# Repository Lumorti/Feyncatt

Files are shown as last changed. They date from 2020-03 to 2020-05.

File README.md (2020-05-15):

# Feyncatt

### Description

An attempt at a robotic quadruped. At the current stage it's fully printed, able to stand upright and do basic leg movements.

Schrödinger was too obvious a name.

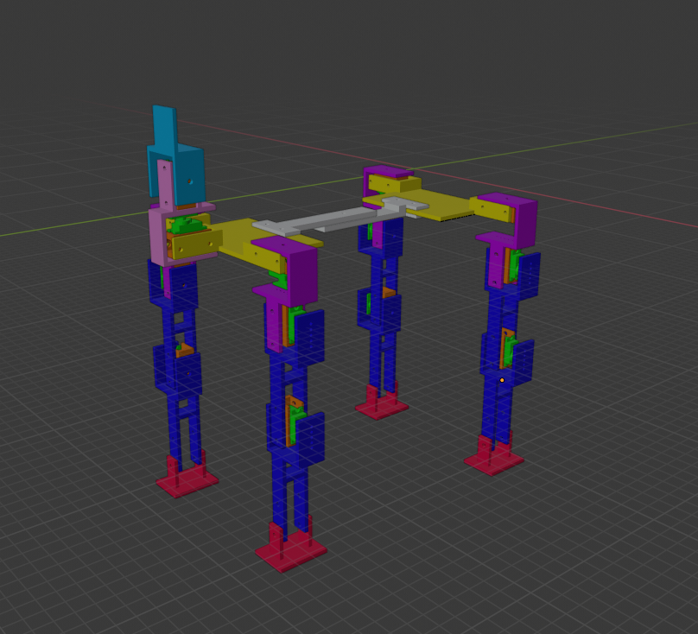
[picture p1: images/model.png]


TODO:
 - attempt a basic walk cycle
 - reprint the feet to be more efficient
 - make the walk cycle more fluid
 - allow turning
 - allow environmental mapping

### Requirements

 - a 3D printer, doesn't need to be a fancy one
 - less than 1 kg of PLA (1 kg allowed me many misprints and redesigns)

 - 14 SG90 servos ([here](https://www.bitsbox.co.uk/index.php?main_page=product_info&cPath=251&products_id=3504))
 - Arduino UNO (or equivalent) ([here](https://www.amazon.co.uk/Arduino-A000066-ARDUINO-UNO-REV3/dp/B008GRTSV6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))
 - MPU6050 Accelerometer/Gyroscope ([here](https://www.bitsbox.co.uk/index.php?main_page=product_info&cPath=302_304&products_id=3059))
 - Ultrasonic range finder ([here](https://www.bitsbox.co.uk/index.php?main_page=product_info&cPath=302_310&products_id=3633))
 - SD card reader and SD card ([here](https://www.bitsbox.co.uk/index.php?main_page=product_info&cPath=347&products_id=2947) and [here](https://www.amazon.co.uk/SanDisk-microSDHC-Memory-Adapter-Performance/dp/B073S9SFK2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))

 - 4xAA battery pack ([here](https://www.bitsbox.co.uk/index.php?main_page=product_info&cPath=192_195_198&products_id=1441))
 - 4 NiMH batteries ([here](https://www.amazon.co.uk/AmazonBasics-Capacity-Pre-Charged-Rechargeable-Batteries-Black/dp/B00HZV9WTM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))
 - boost converter, LCD screen is helpful ([here](https://www.bitsbox.co.uk/index.php?main_page=product_info&cPath=140_171&products_id=3259))
 - 5 A fuse and holder (or not, it's your flammable house) ([here](https://www.bitsbox.co.uk/index.php?main_page=product_info&cPath=214_215_219&products_id=1523) and [here](https://www.bitsbox.co.uk/index.php?main_page=product_info&cPath=214_215_220&products_id=2230))

 - many 1" pin header jumper cables for connecting modules ([here](https://www.bitsbox.co.uk/index.php?main_page=product_info&cPath=225_233&products_id=2909))
 - some wire rated for 5 A as the main power rail ([here](https://www.amazon.co.uk/PsmGoods%C2%AE-Gauge-Silicone-Flexible-Rubber-18/dp/B074299GG5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))
 - switch ([here](https://www.bitsbox.co.uk/index.php?main_page=product_info&cPath=116_136&products_id=911))
 - M4 machine screws/nuts, M3 machine screws/nuts, M2 machine screws/nuts
 
### Printed Parts Required

Can probably all be printed over about a week if you just do a couple parts a day, each part takes about an hour on standard settings.

 - 14 x servoMountV3
 - 8 x servoConnectorStraight
 - 4 x foot
 - 4 x servoConnectorTwist
 - 2 x bodyConnector
 - 1 x bodyBack
 - 1 x bodyFront
 - 1 x servoConnectorHead
 - 1 x servoConnectorNeck

### Build Instructions

- print everything
- figure out all the start/mid/end PWM values for the servos
- assemble the legs
- assemble the body
- assemble the head
- wire up the body
- connect the legs 
- wire up the legs
- connect the head 
- wire up the head
- double check all the wiring
- check it all again
- turn it on, flash the Arduino with the firmware

TODO

### Usage Instructions

TODO

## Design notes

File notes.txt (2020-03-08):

Two main sections of code:
1) neural net trained to recognise certain hand signs
 - follow
 - sleep
 - wait
 - explore
2) code that performs the task specified above by calling functions like "moveForward(10cm)", "turn(-10degrees)", also processes incoming cam data and runs through sobel filter to determine edges, distances etc.

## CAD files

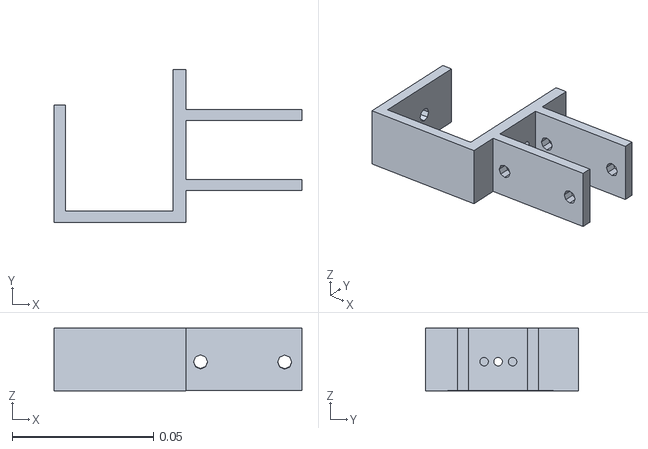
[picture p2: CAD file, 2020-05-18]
stl/servoConnectorNeck.stl
0.0878 x 0.054 x 0.0221

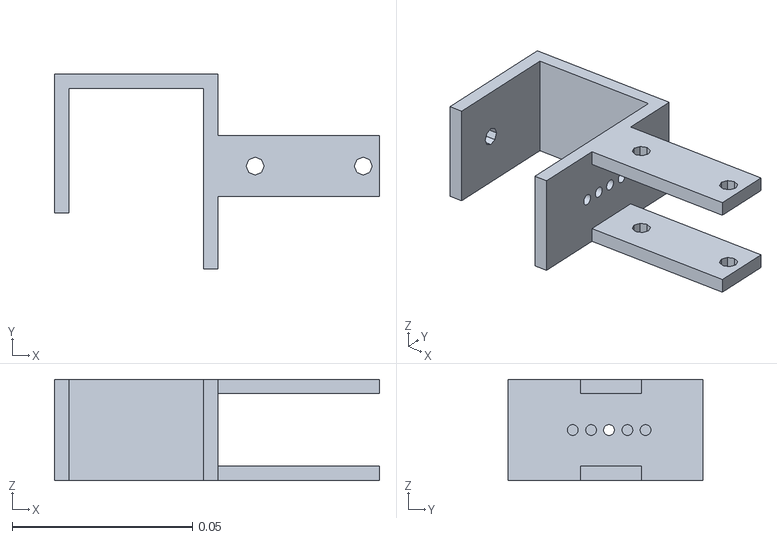
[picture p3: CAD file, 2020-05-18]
stl/servoConnectorTwist.stl
0.0902 x 0.054 x 0.028

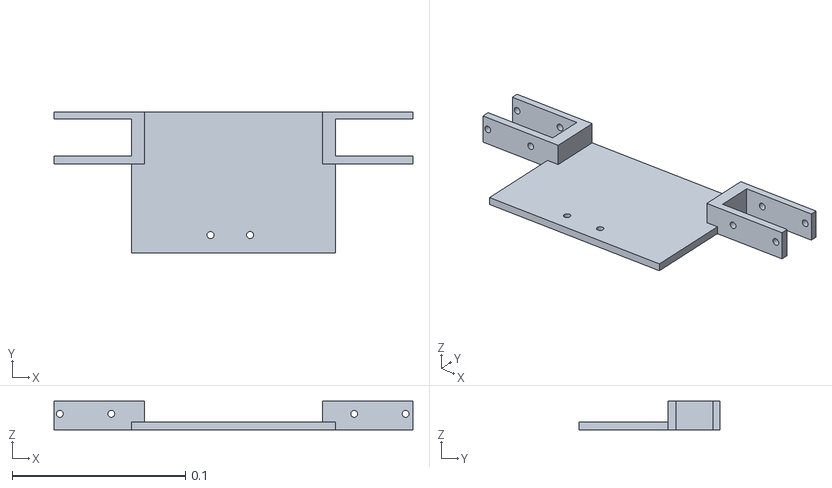
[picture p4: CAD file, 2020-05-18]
stl/bodyBack.stl
0.207 x 0.0816 x 0.0165

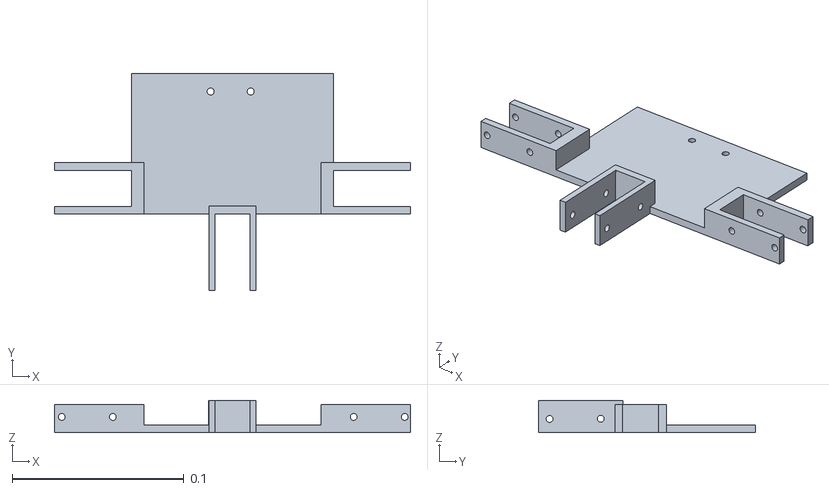
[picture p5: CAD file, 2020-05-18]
stl/bodyFront.stl
0.207 x 0.126 x 0.0189

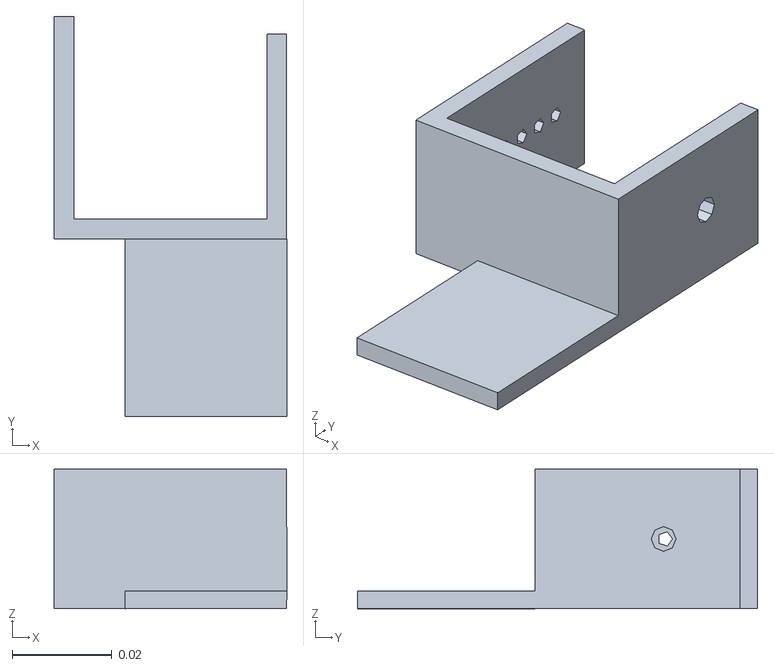
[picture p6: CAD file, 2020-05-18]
stl/servoConnectorHead.stl
0.0467 x 0.0803 x 0.028

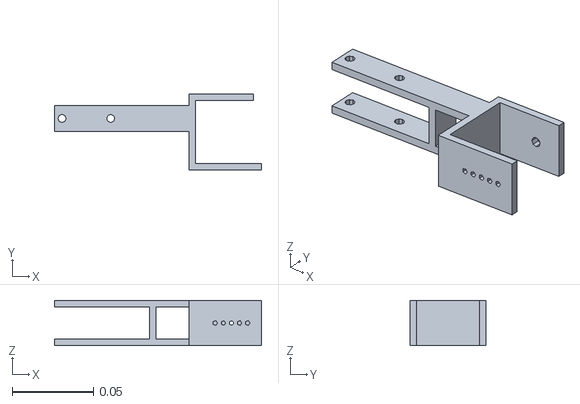
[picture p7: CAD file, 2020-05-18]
stl/servoConnectorStraight.stl
0.128 x 0.0467 x 0.028

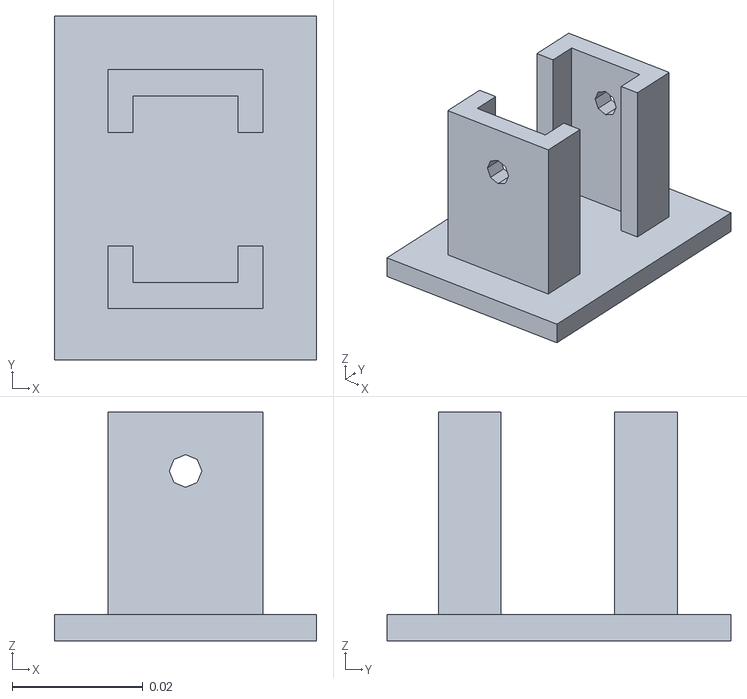
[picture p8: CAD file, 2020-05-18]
stl/footV2.stl
0.0401 x 0.0527 x 0.035

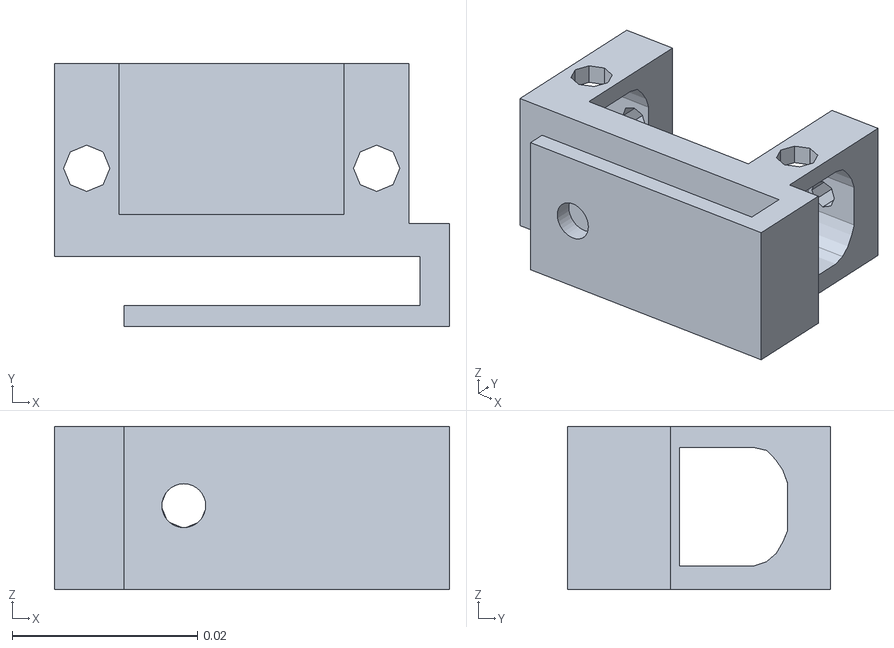
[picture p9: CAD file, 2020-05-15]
stl/servoMountV3.stl
0.0426 x 0.0284 x 0.0176

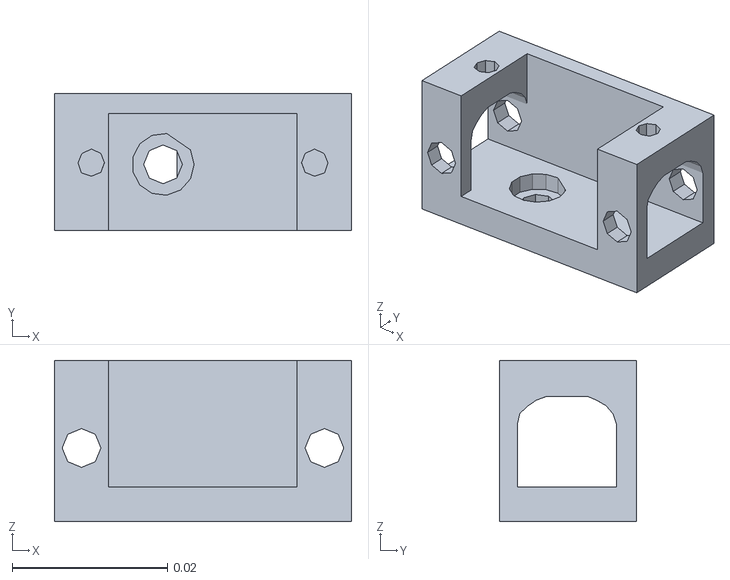
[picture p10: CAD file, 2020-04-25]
stl/servoMountNew.stl
0.0383 x 0.0176 x 0.0208

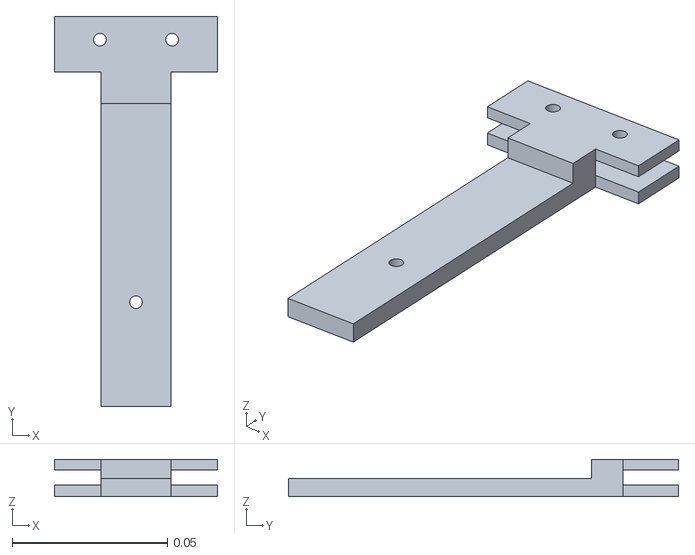
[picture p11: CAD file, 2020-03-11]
stl/bodyConnector.stl
0.0524 x 0.126 x 0.012

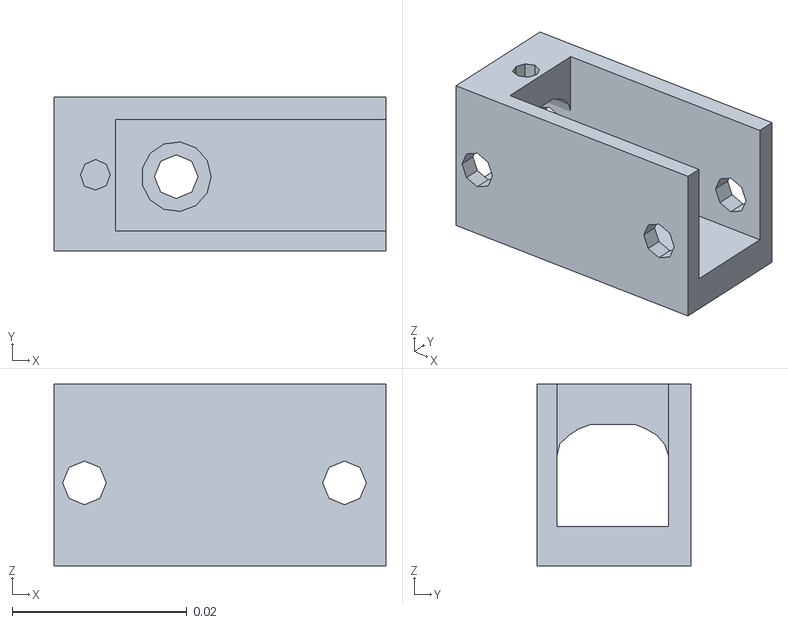
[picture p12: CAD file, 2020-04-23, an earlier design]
stl/servoMount.stl
0.038 x 0.0176 x 0.0208

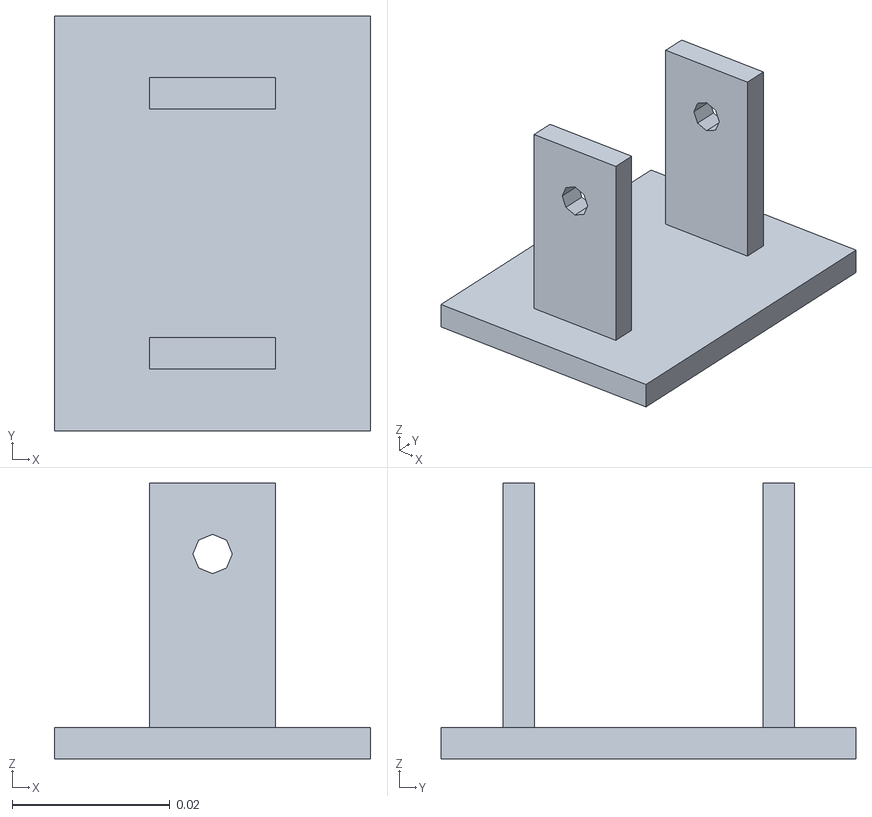
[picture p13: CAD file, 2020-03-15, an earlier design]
stl/foot.stl
0.0401 x 0.0527 x 0.035

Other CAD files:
blender/cat.blend

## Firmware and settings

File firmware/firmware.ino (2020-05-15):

#include <Wire.h>
#include <Adafruit_PWMServoDriver.h>
#include <SD.h>
#include <avr/pgmspace.h>

// Address of the gyro
#define MPU_ADDR 0x68

// Servo properties
#define SERVO_FREQ 50
#define NUM_SERVOS 16
#define QUEUE_SIZE 5
#define NUM_POSITIONS 11
#define AVG_SPEED 100
#define SAVE_POWER false

// Servo pin numbers
#define FRONT_LEFT_HIP      0
#define FRONT_LEFT_KNEE     1
#define FRONT_LEFT_ANKLE    2
#define BACK_LEFT_HIP       4
#define BACK_LEFT_KNEE      5
#define BACK_LEFT_ANKLE     6
#define BACK_RIGHT_HIP      8
#define BACK_RIGHT_KNEE     9
#define BACK_RIGHT_ANKLE    10
#define FRONT_RIGHT_HIP     12
#define FRONT_RIGHT_KNEE    13
#define FRONT_RIGHT_ANKLE   14
#define NECK_VERT           3
#define NECK_HORIZ          15

// Position numbers
#define STOOD_STRAIGHT          0
#define FRONT_LEFT_LEG_UP       1
#define FRONT_RIGHT_LEG_UP      2

// Min and max values for each servo, tweak as necessary
const short minPWM[NUM_SERVOS]   PROGMEM = {110, 120, 120, 0, 130, 150, 110, 0, 105, 120, 120, 0, 120, 120, 110, 0};
const short midPWM[NUM_SERVOS]   PROGMEM = {290, 310, 315, 0, 325, 345, 305, 0, 310, 315, 325, 0, 325, 320, 310, 0};
const short maxPWM[NUM_SERVOS]   PROGMEM = {530, 520, 520, 0, 500, 545, 555, 0, 510, 520, 560, 0, 540, 520, 555, 0};
const short minAngle[NUM_SERVOS] PROGMEM = {-30, -90, -90, 0, -30, -90, -90, 0, -30, -90, -90, 0, -30, -90, -90, 0};
const short maxAngle[NUM_SERVOS] PROGMEM = { 30,  90,  90, 0,  30,  90,  90, 0,  30,  90,  90, 0,  30,  90,  90, 0};

const short positions[NUM_POSITIONS][NUM_SERVOS] PROGMEM = {

  // STOOD_STRAIGHT
  {0,   0,   0, 0, 0,   0,   0, 0, 0,   0,   0,  0, 0,   0,   0, 0},

  // FRONT_LEFT_UP
  {0,  45, -45, 0, 0,   0,   0, 0, 0,   0,   0,  0, 0,   0,   0, 0},
  // FRONT_RIGHT_UP
  {0,   0,   0, 0, 0,   0,   0, 0, 0,   0,   0,  0, 0, -45,  45, 0},
  // BACK_LEFT_UP
  {0,   0,   0, 0, 0,  45, -45, 0, 0,   0,   0,  0, 0,   0,   0, 0},
  // BACK_RIGHT_UP
  {0,   0,   0, 0, 0,   0,   0, 0, 0, -45,  45,  0, 0,   0,   0, 0},

  // WALK1 = FRONT_RIGHT_UP + BACK_LEFT_UP
  {0,   0,   0, 0, 0,  45, -45, 0, 0,   0,   0,  0, 0, -45,  45, 0},

  // WALK2 = FRONT_RIGHT_UP + BACK_LEFT_UP - FRONT_LEFT_UP - BACK_RIGHT_UP
  {0, -45,  45, 0, 0,  45, -45, 0, 0,  45, -45,  0, 0, -45,  45, 0},

  // WALK3 = - FRONT_LEFT_UP - BACK_RIGHT_UP
  {0, -45,  45, 0, 0,   0,   0, 0, 0,  45, -45,  0, 0,   0,   0, 0},

  // WALK1_ALT = FRONT_LEFT_UP + BACK_RIGHT_UP
  {0,  45, -45, 0, 0,   0,   0, 0, 0, -45,  45,  0, 0,   0,   0, 0},

  // WALK2_ALT = FRONT_LEFT_UP + BACK_RIGHT_UP - FRONT_RIGHT_UP - BACK_LEFT_UP
  {0,  45, -45, 0, 0, -45,  45, 0, 0, -45,  45,  0, 0,  45, -45, 0},

  // WALK3_ALT =  - FRONT_RIGHT_UP - BACK_LEFT_UP
  {0,   0,   0, 0, 0, -45,  45, 0, 0,   0,   0,  0, 0,  45, -45, 0},


};

// Main servo controller
Adafruit_PWMServoDriver pwm = Adafruit_PWMServoDriver();

// For I/O
String soFar;
int newValue;
int motorNum;
char incomingByte;

// For accelerometer data
float accelData[3];

// For storing the current angle and the queue of positions
float currentAngles[NUM_SERVOS];
float deltas[NUM_SERVOS];
int stepsLeft = 0;
int numInQueue = 0;
int queue[QUEUE_SIZE * 2];

// Change a servo to an angle
void setServoAngle(uint8_t servoNum, double angle) {

  int actualAngle = min(max(angle, pgm_read_word_near(minAngle + servoNum)), pgm_read_word_near(maxAngle + servoNum));

  if (actualAngle < 0) {
    pwm.setPWM(servoNum, 0, map(actualAngle, -90, 0, pgm_read_word_near(minPWM + servoNum), pgm_read_word_near(midPWM + servoNum)));
  }
  else {
    pwm.setPWM(servoNum, 0, map(actualAngle, 0, 90, pgm_read_word_near(midPWM + servoNum), pgm_read_word_near(maxPWM + servoNum)));
  }

}

void servoStep() {

  // If still have movements to make
  if (stepsLeft > 0) {

    for (int i = 0; i < NUM_SERVOS; i++) {

      currentAngles[i] = currentAngles[i] + deltas[i];

      // Keep any centred servos limp to save power
      if (abs(currentAngles[i]) > 1 || !SAVE_POWER) {
        setServoAngle(i, currentAngles[i]);
      }
      else {
        pwm.setPWM(i, 0, 0);
      }

    }

    stepsLeft = stepsLeft - 1;

  // Otherwise calculate the new deltas
  } else if (numInQueue > 0) {

    stepsLeft = queue[1];
    for (int i = 0; i < NUM_SERVOS; i++) {
      deltas[i] = (float(pgm_read_word_near(&(positions[queue[0]][i]))) - currentAngles[i]) / float(stepsLeft);
    }

    // Shift the queue along
    for (int i = 0; i < QUEUE_SIZE*2 - 2; i += 2) {

      queue[i] = queue[i + 2];
      queue[i + 1] = queue[i + 3];

    }

    numInQueue = numInQueue - 1;

    if (Serial) {
      Serial.println(F("new deltas:"));
      printFloatArray(deltas, NUM_SERVOS);
      Serial.println(F("new queue (removed):"));
      printIntArray(queue, QUEUE_SIZE * 2);
    }

  }

}

void printIntArray(int toPrint[], int arraySize) {

  for (int i = 0; i < arraySize - 1; i++) {
    Serial.print(toPrint[i]);
    Serial.print(", ");
  }
  Serial.println(toPrint[arraySize - 1]);

}

void printFloatArray(float toPrint[], int arraySize) {

  for (int i = 0; i < arraySize - 1; i++) {
    Serial.print(toPrint[i]);
    Serial.print(", ");
  }
  Serial.println(toPrint[arraySize - 1]);

}

// Add a position to the end of the queue
void addToQueue(int pos, int steps) {

  queue[numInQueue * 2] = pos;
  queue[numInQueue * 2 + 1] = steps;
  numInQueue = numInQueue + 1;

  if (Serial) {
    Serial.println("new queue (added):");
    printIntArray(queue, QUEUE_SIZE * 2);
  }

}

// Retrieves the x/y/z accelerometer data
void getAccelData(float values[]) {

  // Accel data
  Wire.beginTransmission(MPU_ADDR);
  Wire.write(0x3B);
  Wire.endTransmission(false);
  Wire.requestFrom(MPU_ADDR, 6, true);
  values[0] = (Wire.read() << 8 | Wire.read()) / 16384.0;
  values[1] = (Wire.read() << 8 | Wire.read()) / 16384.0;
  values[2] = (Wire.read() << 8 | Wire.read()) / 16384.0;

}

void gatherInfo() {}
void updateActions() {}

void setup() {

  // Setup servo control
  pwm.begin();
  pwm.setPWMFreq(SERVO_FREQ);

  // Setup serial comms
  if (Serial) {

    Serial.begin(9600);
    while (!Serial);
    Serial.flush();
    Serial.println(F("started"));

  }

  // Setup SD card reading
  if (!SD.begin()) {
    if (Serial) {
      Serial.println(F("ERROR - SD card init failed"));
    }
  }

  // Setup and wake the accelerometer
  Wire.begin();
  Wire.beginTransmission(MPU_ADDR);
  Wire.write(0x6B);
  Wire.write(0);
  Wire.endTransmission(true);

  // Reset all servos
  for (int i = 0; i < NUM_SERVOS; i++) {

    currentAngles[i] = 0;
    setServoAngle(i, currentAngles[i]);

  }

  delay(100);

  // Limp all servos
  for (int i = 0; i < NUM_SERVOS; i++) {pwm.setPWM(i, 0, 0);}

}

void loop() {

  if (Serial.available() > 0) {

    incomingByte = Serial.read();

    if (int(incomingByte) == 10) {

      if (soFar[0] == '#') {

        newValue = soFar.substring(1).toInt();
        soFar = "";
        Serial.print(F("Setting to position number "));
        Serial.println(newValue);
        addToQueue(newValue, AVG_SPEED);

      } else {

        newValue = soFar.toInt();
        soFar = "";
        Serial.print(F(" to "));
        Serial.println(newValue);
        pwm.setPWM(motorNum, 0, newValue);

      }

    } else if (int(incomingByte) == 32) {

      motorNum = soFar.toInt();
      soFar = "";
      Serial.print(F("Setting motor "));
      Serial.print(motorNum);

    } else {
      soFar = soFar + incomingByte;
    }

  }

  gatherInfo();
  updateActions();
  servoStep();
  delay(5);

}

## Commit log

2019-11-13 finished leg model
    [motor.scad]
2020-03-05 migrated to blender
    [cat.blend, motor.scad, motor.stl]
2020-03-06 added body motor connectors
    [cat.blend]
2020-03-07 removed obselete files
    [motor.scad, motor.stl]
2020-03-08 added middle linkage and new notes file
    [cat.blend]
2020-03-11 first draft of full body completed
    [cat.blend]
2020-03-11 added basic test firmware
    [cat.blend]
2020-03-11 move blender files to their own folder
    [cat.blend]
2020-03-11 added stl and gcode files
    [bodyBack.stl, bodyConnector.stl, bodyFront.stl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]
2020-03-15 motor mount revamp
    [cat.blend, foot.stl, servoMount.stl]
2020-03-17 added missing holes
    [cat.blend]
2020-03-17 added motor resetting function to firmware
    [firmware.ino]
2020-04-23 slight motor mount size tweak
    [cat.blend, servoMount.stl]
2020-04-25 trying new motor mount design
    [cat.blend, servoMountNew.stl]
2020-05-15 started work on walk cycles
    [cat.blend, servoMountV3.stl]
2020-05-18 made various tweaks to parts after assembling the thing
    [bodyBack.stl, bodyFront.stl, cat.blend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]
